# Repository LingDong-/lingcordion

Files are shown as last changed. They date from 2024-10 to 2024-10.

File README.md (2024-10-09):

# Lingcordion

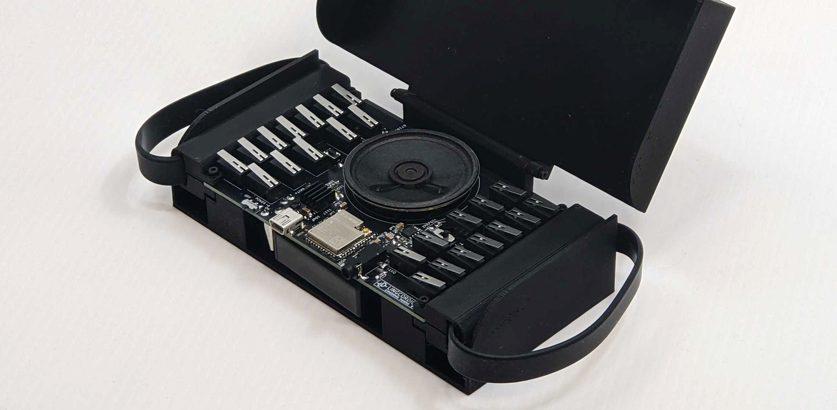
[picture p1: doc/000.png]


A pocket-sized digital musical instrument inspired by the piano and the accordion.

This repo hosts the design files of the PCB, source code for the firmware, and CAD parts for 3D printing.

## Features

- 3 playable octaves on the right hand, bass/chord mode on the left hand.
- On-board synthesizer / MIDI output (USB).
- On-board speaker / 3.5mm audio jack.
- Easy to learn, fits in your back pocket.

## How to Play

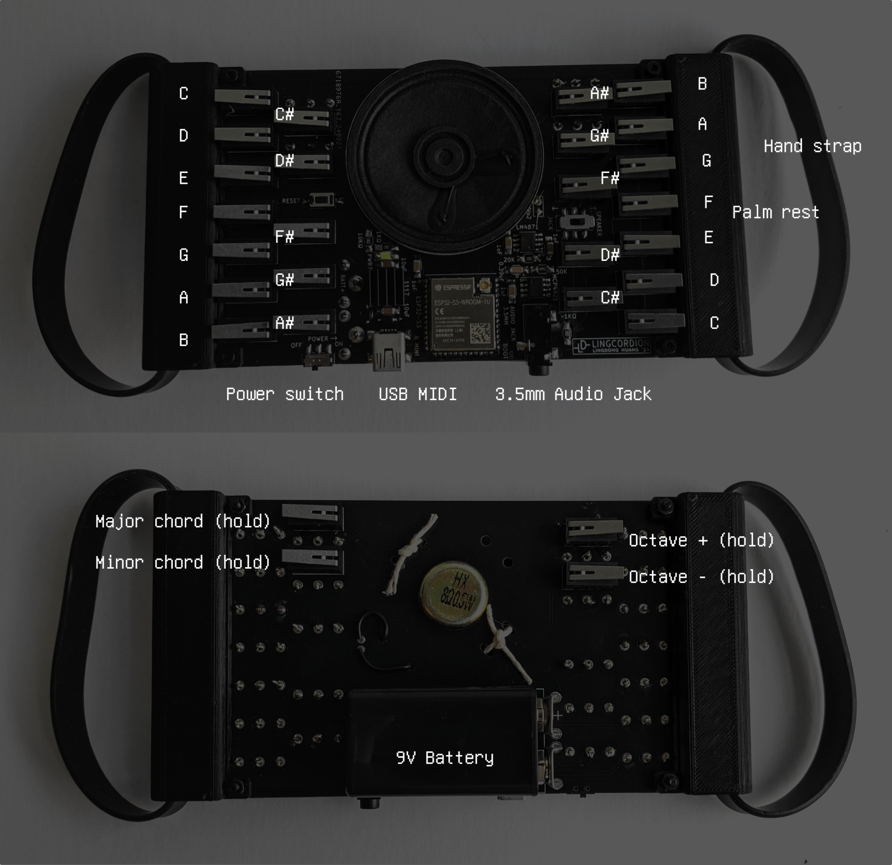
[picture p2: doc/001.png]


[Here's a video of me playing the instrument.](doc/v01.mp4)

https://github.com/user-attachments/assets/264b68fd-24f3-4782-8792-03d39f5a074a

- The index, middle, ring and (optionally) pinky fingers go between the strap and the palm rest, to play note keys on the front side.
- The thumbs press and hold modifier keys on the back side.

## BOM

- 28 limit switches
- ESP32-S3 module with more than 4 MB of flash
- LM4871 for audio power amplifier
- MCP4921 for DAC
- Assorted 1206 resistors capacitors. Misc. buttons and switches. 1117 3.3V regulator.

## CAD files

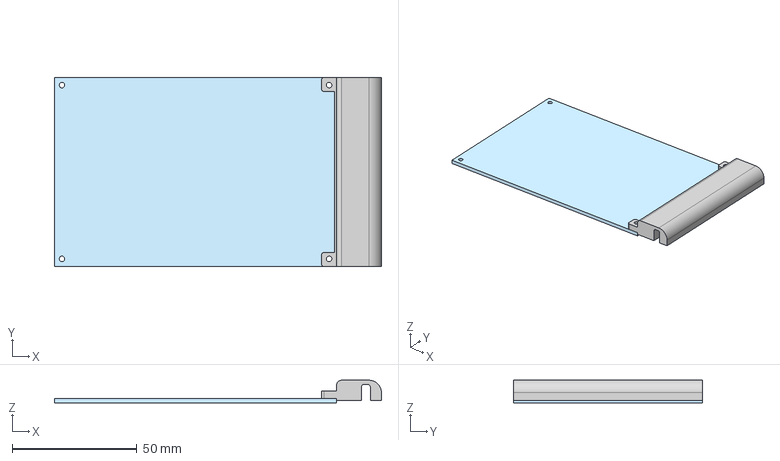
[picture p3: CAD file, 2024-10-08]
parts/rest.step
131.0 x 75.6 x 9.05 mm

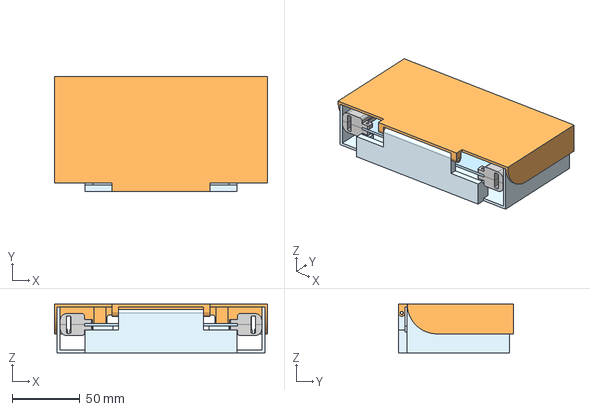
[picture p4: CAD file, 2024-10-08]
parts/case.step
157.4 x 85.1 x 36.0 mm

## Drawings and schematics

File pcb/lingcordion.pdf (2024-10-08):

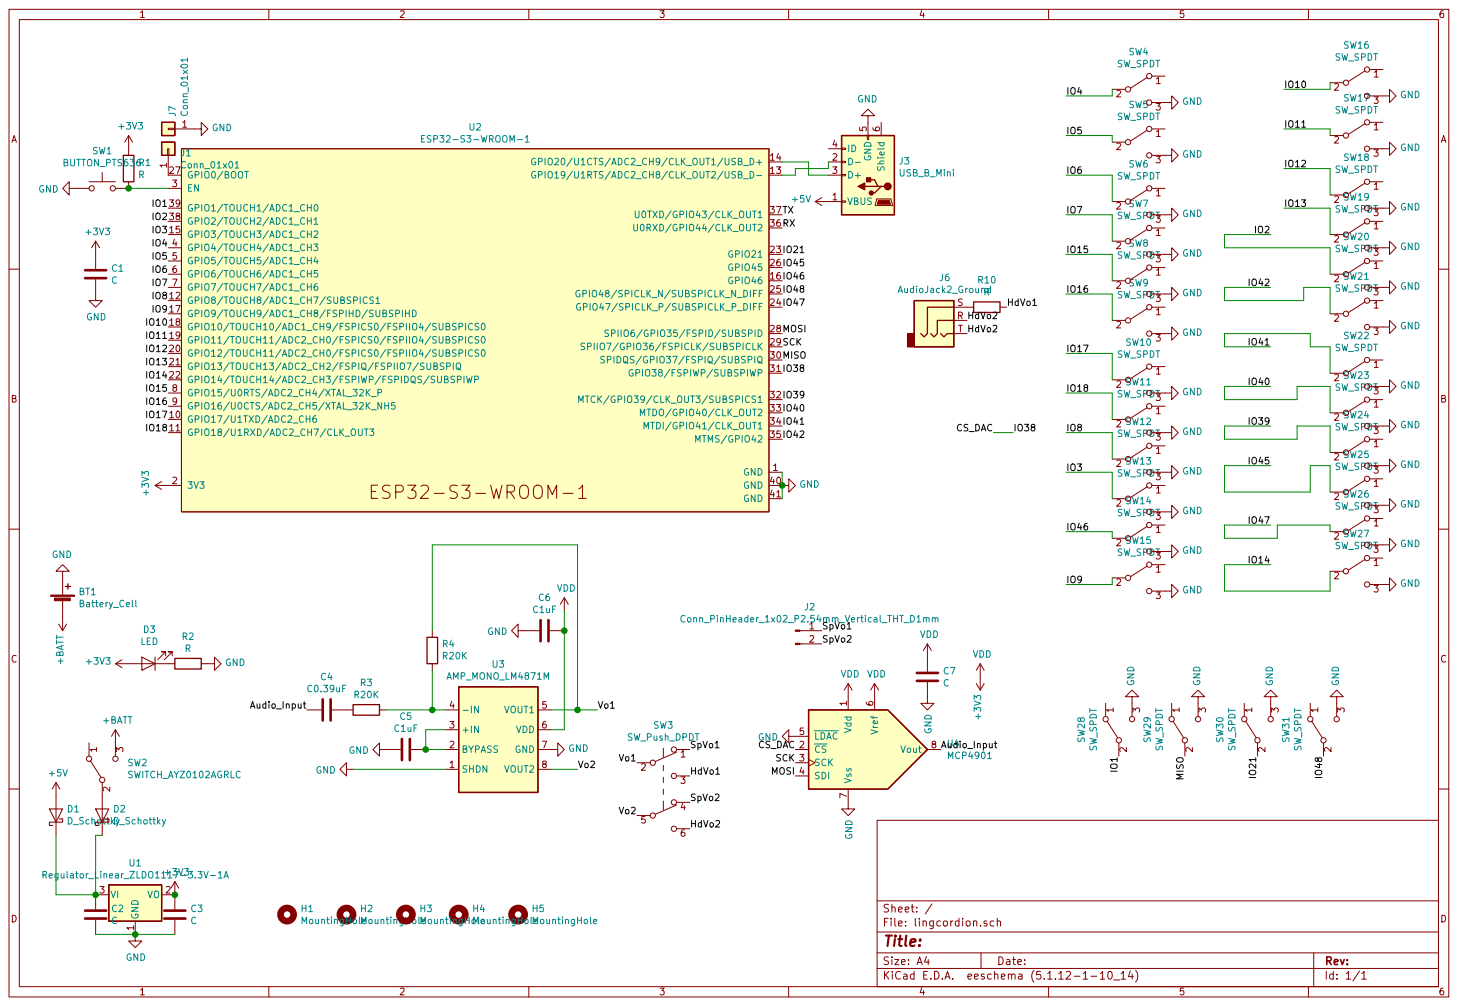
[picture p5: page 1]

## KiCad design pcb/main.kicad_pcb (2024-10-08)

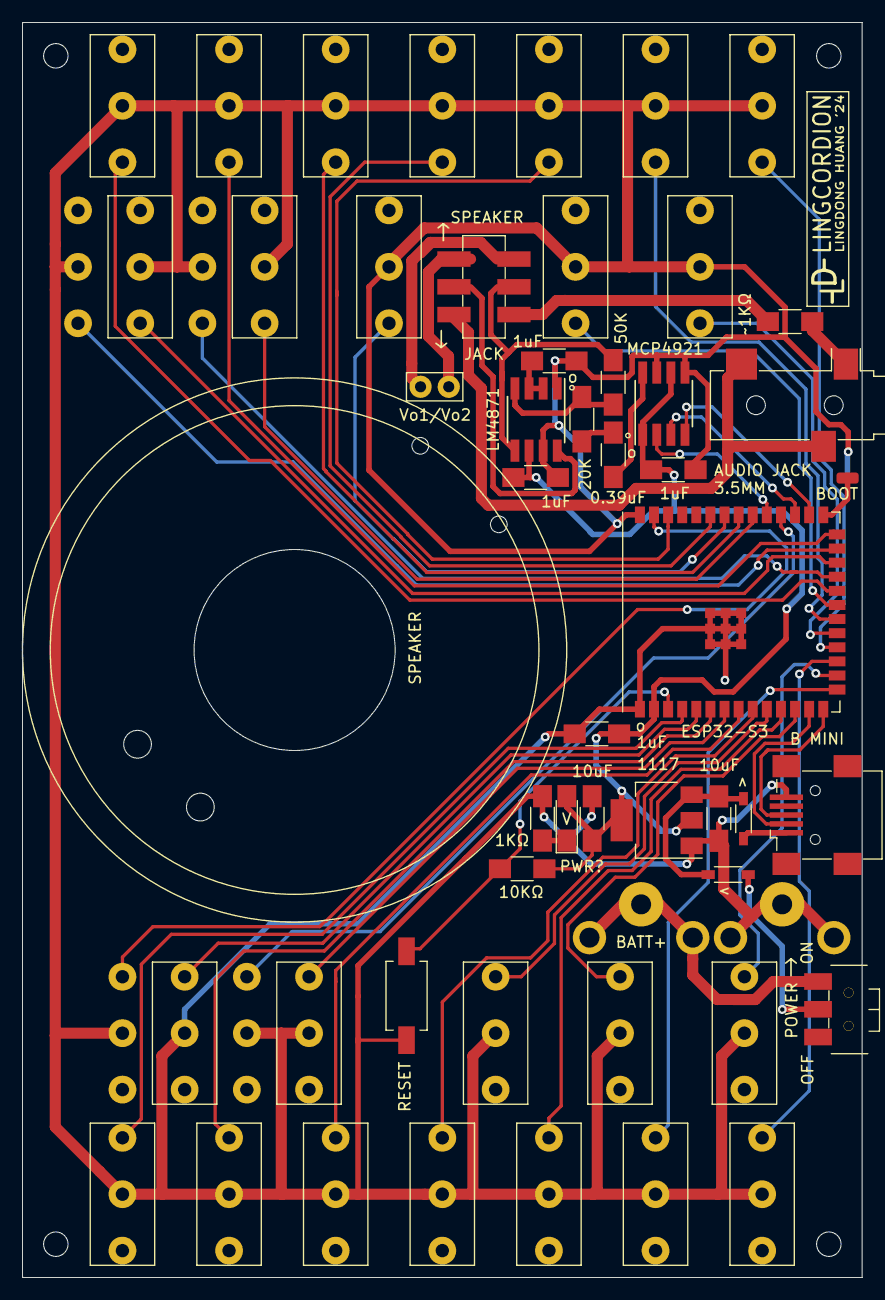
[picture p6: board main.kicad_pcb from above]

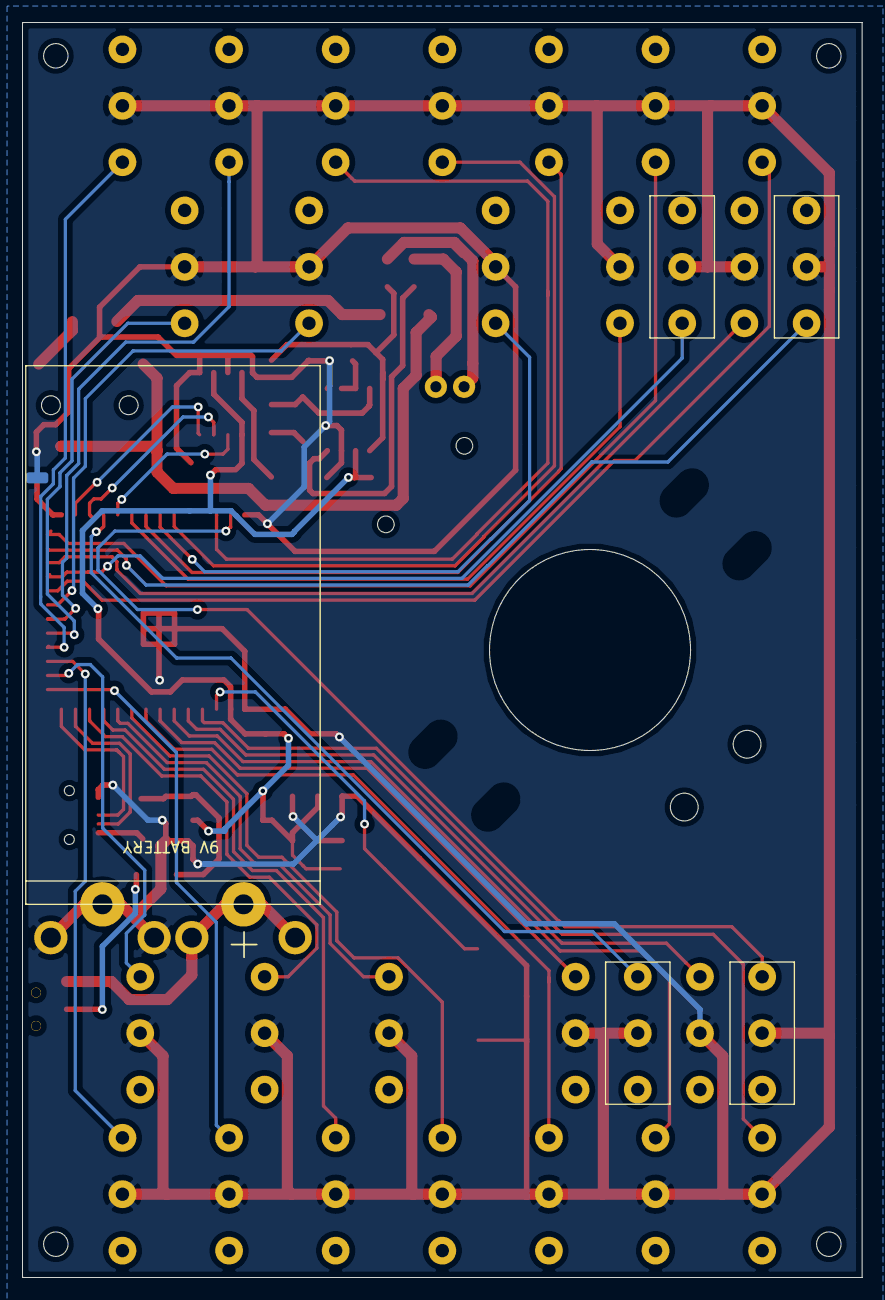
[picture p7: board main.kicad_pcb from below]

Board: 2 copper layers, 75.6 x 113.0 mm, 61 parts (6 on the bottom side), 53 nets.

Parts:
BT1: Battery_Cell; 9V_CONTACT_ON_BRD
C1, C2, C3, C7: C; C_1206
C4: C0.39uF; C_1206
C5, C6: C1uF; C_1206
D1, D2: D_Schottky; SOD-123
D3: LED; LED_1206
H1: MountingHole; SPEAKER_MOUNT
H2, H3, H4, H5: MountingHole; MountingHole_2.2mm_M2
J1, J7: Conn_01x01; SolderWirePad_1x01_SMD_1x2mm
J2: Conn_PinHeader_1x02_P2.54mm_Vertical_THT_D1mm; PinHeader_1x02_P2.54mm_Vertical_THT_D1mm
J3: USB_B_Mini; USB_Mini-B_Wuerth_65100516121_Horizontal
J6: AudioJack2_Ground; Jack_3.5mm_CUI_SJ-3523-SMT_Horizontal
R1, R2, R10: R; R_1206
R3, R4: R20K; R_1206
SW1: BUTTON_PTS636; Button_C&K_PTS636_6x3.5mm
SW2: SWITCH_AYZ0102AGRLC; Switch_SPDT_C&K_AYZ0102AGRLC_7.2x3mm_P2.5mm
SW3: SW_Push_DPDT; SW_DPDT_CK_JS202011JCQN
SW4, SW5, SW6, SW7, SW8, SW9, SW10, SW11, SW12, SW13, SW14, SW15, SW16, SW17, SW18, SW19, SW20, SW21, SW22, SW23, SW24, SW25, SW26, SW27, SW28, SW29, SW30, SW31: SW_SPDT; LIMIT_SWITCH_TE_SAJ
U1: Regulator_Linear_ZLDO1117-3.3V-1A; SOT-223-3_TabPin2
U2: ESP32-S3-WROOM-1
U3: AMP_MONO_LM4871M; SOIC-8_3.9x4.9mm_P1.27mm
U4: MCP4901; SOIC-8_3.9x4.9mm_P1.27mm

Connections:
+3V3: C1.1, C3.1, C6.1, C7.1, D3.2, R1.1, U1.2, U2.2, U3.6, U4.1, U4.6
+5V: D1.2, J3.1
+BATT: BT1.2, SW2.3
/Audio_Input: C4.2, U4.8
/CS_DAC: U2.31, U4.2
/HdVo1: R10.1, SW3.3
/HdVo2: J6.R, J6.T, SW3.6
/IO1: SW28.2, U2.39
/IO2: SW20.2, U2.38
/IO3: SW13.2, U2.15
/IO4: SW4.2, U2.4
/IO5: SW5.2, U2.5
/IO6: SW6.2, U2.6
/IO7: SW7.2, U2.7
/IO8: SW12.2, U2.12
/IO9: SW15.2, U2.17
/IO10: SW16.2, U2.18
/IO11: SW17.2, U2.19
/IO12: SW18.2, U2.20
/IO13: SW19.2, U2.21
/IO14: SW27.2, U2.22
/IO15: SW8.2, U2.8
/IO16: SW9.2, U2.9
/IO17: SW10.2, U2.10
/IO18: SW11.2, U2.11
/IO21: SW30.2, U2.23
/IO39: SW24.2, U2.32
/IO40: SW23.2, U2.33
/IO41: SW22.2, U2.34
/IO42: SW21.2, U2.35
/IO45: SW25.2, U2.26
/IO46: SW14.2, U2.16
/IO47: SW26.2, U2.24
/IO48: SW31.2, U2.25
/MISO: SW29.2, U2.30
/MOSI: U2.28, U4.4
/SCK: U2.29, U4.3
/SpVo1: J2.1, SW3.1
/SpVo2: J2.2, SW3.4
/Vo1: R4.2, SW3.2, U3.5
/Vo2: SW3.5, U3.8
GND: BT1.1, C1.2, C2.2, C3.2, C5.2, C6.2, C7.2, J3.5, J7.1, R2.1, SW1.1, SW4.3, SW5.3, SW6.3, SW7.3, SW8.3, SW9.3, SW10.3, SW11.3, SW12.3, SW13.3, SW14.3, SW15.3, SW16.3, SW17.3, SW18.3, SW19.3, SW20.3, SW21.3, SW22.3, SW23.3, SW24.3, SW25.3, SW26.3, SW27.3, SW28.3, SW29.3, SW30.3, SW31.3, U1.1, U2.1, U2.40, U2.41, U3.1, U3.7, U4.5, U4.7
unnamed: C2.1, D1.1, D2.1, U1.3
unnamed: C4.1, R3.2
unnamed: C5.1, U3.2, U3.3
unnamed: D2.2, SW2.2
unnamed: D3.1, R2.2
unnamed: J1.1, U2.27
unnamed: J3.2, U2.13
unnamed: J3.3, U2.14
unnamed: J6.S, R10.2
unnamed: R1.2, SW1.2, U2.3
unnamed: R3.1, R4.1, U3.4

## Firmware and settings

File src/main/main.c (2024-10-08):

#include <stdio.h>
#include <inttypes.h>
#include <string.h>
#include <math.h>
#include <dirent.h>
#include "sdkconfig.h"
#include "freertos/FreeRTOS.h"
#include "freertos/task.h"
#include "driver/spi_master.h"
#include "driver/gpio.h"
#include "esp_system.h"
#include "nvs_flash.h"
#include "driver/uart.h"

#include "tinyusb.h"

#include "esp_timer.h"


#define PIN_MOSI (35)
#define PIN_CLK  (36)
#define PIN_DACS (38)


#define PIN_OP (1)
#define PIN_OM (37)
#define PIN_CH (48)
#define PIN_BO (21)

#define MIDI_NOTE_OFF 0x80
#define MIDI_NOTE_ON  0x90

#define N_KEY 24

typedef struct key_st{
  uint8_t pitch;
  uint8_t flag;
  uint16_t onoff;
  uint16_t plyhd;
} KEY_t;

KEY_t keys[N_KEY]={0};

#define SAMP_RATE 8000

#define SAMP_PER_KEY 16000

#define TAPER 1000

spi_device_handle_t spi;

#define N_TBTN 24
static const int tbtn[N_TBTN] = {
  10,11,12,13,2,42,41,40,39,45,47,14,
  4,5,6,7,15,16,17,18,8,3,46,9
};



uint8_t tbtn_prev[N_TBTN] = {0};

int op_prv = 1;
int om_prv = 1;

int ch_prv = 1;
int bo_prv = 1;

#define GETSAMP(p) {\
  int idx = (((p)-21)*SAMP_PER_KEY+b)*2;\
  int A = ((uint8_t*)salaman)[idx];\
  int B = ((uint8_t*)salaman)[idx+1];\
  int16_t C = (A|(B<<8));\
  y = (float)C/32768.0;\
}


enum interface_count {
  ITF_NUM_MIDI = 0,
  ITF_NUM_MIDI_STREAMING,
  ITF_COUNT
};
enum usb_endpoints {
  EP_EMPTY = 0,
  EPNUM_MIDI,
};
#define TUSB_DESCRIPTOR_TOTAL_LEN (TUD_CONFIG_DESC_LEN + CFG_TUD_MIDI * TUD_MIDI_DESC_LEN)
static const char* s_str_desc[5] = {
  (char[]){0x09, 0x04},  // 0: is supported language is English (0x0409)
  "Lingdong Huang",      // 1: Manufacturer
  "Lingcordion",         // 2: Product
  "123456",              // 3: Serials, should use chip ID
  "MIDI device",         // 4: MIDI
};

static const uint8_t s_midi_cfg_desc[] = {
  TUD_CONFIG_DESCRIPTOR(1, ITF_COUNT, 0, TUSB_DESCRIPTOR_TOTAL_LEN, 0, 100),
  TUD_MIDI_DESCRIPTOR(ITF_NUM_MIDI, 4, EPNUM_MIDI, (0x80 | EPNUM_MIDI), 64),
};

void midi_note_on(int pitch, int vel){
  if (tud_midi_mounted()) {
    static uint8_t const cable_num = 0;
    static uint8_t const channel = 0;
    uint8_t note_on[3] = {MIDI_NOTE_ON | channel, pitch, vel};
    tud_midi_stream_write(cable_num, note_on, 3);
  }
}
void midi_note_off(int pitch){
  if (tud_midi_mounted()) {
    static uint8_t const cable_num = 0;
    static uint8_t const channel = 0;
    uint8_t note_off[3] = {MIDI_NOTE_OFF | channel, pitch, 0};
    tud_midi_stream_write(cable_num, note_off, 3);
  }
}

void core1_task(){
  tinyusb_config_t const tusb_cfg = {
    .device_descriptor = NULL,
    .string_descriptor = s_str_desc,
    .external_phy = false,
    .configuration_descriptor = s_midi_cfg_desc,
  };
  ESP_ERROR_CHECK(tinyusb_driver_install(&tusb_cfg));

  int idx = 0;
  uint8_t btn_prev[N_TBTN] = {0};
  int pit_prev[N_TBTN] = {0};

  while (1){
    int op = gpio_get_level(PIN_OP);
    int om = gpio_get_level(PIN_OM);
    int ch = gpio_get_level(PIN_CH);
    int bo = gpio_get_level(PIN_BO);

    int touch_value = gpio_get_level(tbtn[idx]);

    if (!touch_value && btn_prev[idx]){
      int p = 48+idx;
      if (idx < 12){
        if (!ch){
          midi_note_on(p,96);
          midi_note_on(p+4,96);
          midi_note_on(p+7,96);
          pit_prev[idx] = 0x100|p;
        }else if (!bo){
          midi_note_on(p,96);
          midi_note_on(p+3,96);
          midi_note_on(p+7,96);
          pit_prev[idx] = 0x200|p;
        }else{
          midi_note_on(p,96);
          pit_prev[idx] = p;
        }
      }else{
        if (!op){
          p += 12;
        }else if (!om){
          p -= 12;
        }
        midi_note_on(p,127);
        pit_prev[idx] = p;
      }

    }else if (touch_value  && !btn_prev[idx]){
      int p  = pit_prev[idx];
      if (p & 0x100){
        midi_note_off(p);
        midi_note_off(p+4);
        midi_note_off(p+7);
      }else if (p & 0x200){
        midi_note_off(p);
        midi_note_off(p+3);
        midi_note_off(p+7);
      }else{
        midi_note_off(p);
      }
    }
    btn_prev[idx] = touch_value;
    idx = (idx+1)%N_TBTN;
  }
}


void app_main(void){  


  const esp_partition_t* datapart = esp_partition_find_first(ESP_PARTITION_TYPE_DATA, ESP_PARTITION_SUBTYPE_DATA_UNDEFINED, "data");

  const void* salaman;
  esp_partition_mmap_handle_t handle;
  ESP_ERROR_CHECK(esp_partition_mmap(
      datapart,
      0,
      2848000,
      ESP_PARTITION_MMAP_DATA,
      &salaman,
      &handle
  ));

  for (int i = 0; i < N_TBTN; i++) {
    gpio_config_t io_conf;
    io_conf.intr_type = GPIO_INTR_DISABLE;
    io_conf.mode = GPIO_MODE_INPUT;
    io_conf.pin_bit_mask = (1ULL << tbtn[i]);
    io_conf.pull_down_en = GPIO_PULLDOWN_DISABLE;
    io_conf.pull_up_en = GPIO_PULLUP_ENABLE;     
    gpio_config(&io_conf);

    tbtn_prev[i] = 1;
  }


  esp_err_t ret;
  spi_bus_config_t buscfg={
    .miso_io_num=-1,
    .mosi_io_num=PIN_MOSI,
    .sclk_io_num=PIN_CLK,
    .quadwp_io_num=-1,
    .quadhd_io_num=-1,
    .max_transfer_sz=32
  };
  spi_device_interface_config_t devcfg={
    .clock_speed_hz=20*1000*1000, 
    .mode=0,                               
    .spics_io_num=PIN_DACS,  
    .flags=0,
    .queue_size=7,                      
  };
  ret=spi_bus_initialize(SPI2_HOST, &buscfg, SPI_DMA_CH_AUTO);
  ESP_ERROR_CHECK(ret);
  ret=spi_bus_add_device(SPI2_HOST, &devcfg, &spi);
  ESP_ERROR_CHECK(ret);


  {
    gpio_config_t io_conf;
    io_conf.intr_type = GPIO_INTR_DISABLE;
    io_conf.mode = GPIO_MODE_INPUT;
    io_conf.pin_bit_mask = (1ULL << PIN_OP);
    io_conf.pull_down_en = GPIO_PULLDOWN_DISABLE;
    io_conf.pull_up_en = GPIO_PULLUP_ENABLE;     
    gpio_config(&io_conf);
  }{
    gpio_config_t io_conf;
    io_conf.intr_type = GPIO_INTR_DISABLE;
    io_conf.mode = GPIO_MODE_INPUT;
    io_conf.pin_bit_mask = (1ULL << PIN_OM);
    io_conf.pull_down_en = GPIO_PULLDOWN_DISABLE;
    io_conf.pull_up_en = GPIO_PULLUP_ENABLE;     
    gpio_config(&io_conf);
  }{
    gpio_config_t io_conf;
    io_conf.intr_type = GPIO_INTR_DISABLE;
    io_conf.mode = GPIO_MODE_INPUT;
    io_conf.pin_bit_mask = (1ULL << PIN_CH);
    io_conf.pull_down_en = GPIO_PULLDOWN_DISABLE;
    io_conf.pull_up_en = GPIO_PULLUP_ENABLE;     
    gpio_config(&io_conf);
  }{
    gpio_config_t io_conf;
    io_conf.intr_type = GPIO_INTR_DISABLE;
    io_conf.mode = GPIO_MODE_INPUT;
    io_conf.pin_bit_mask = (1ULL << PIN_BO);
    io_conf.pull_down_en = GPIO_PULLDOWN_DISABLE;
    io_conf.pull_up_en = GPIO_PULLUP_ENABLE;     
    gpio_config(&io_conf);
  }

  uint8_t buf[2];
  spi_transaction_t tr;
  memset(&tr,0,sizeof(tr));
  tr.tx_buffer = buf;
  tr.length = 16;
  tr.flags = 0;  

  int tidx = 0;

  for (int i = 0; i < 24; i++){
    keys[i].pitch = 48+i;
  }


  xTaskCreatePinnedToCore(core1_task, "Core 1", 16384, NULL, 6, NULL, 1);

  while (1){
    int64_t start_time = esp_timer_get_time();

    int op = gpio_get_level(PIN_OP);
    int om = gpio_get_level(PIN_OM);
    int ch = gpio_get_level(PIN_CH);
    int bo = gpio_get_level(PIN_BO);

    float mag = 0;
    for (int j = 0; j < N_KEY; j++){
      if (keys[j].onoff){
        int b = keys[j].plyhd;
        float y = 0;
        if (b < SAMP_PER_KEY){
          int p = keys[j].pitch;
          if (j >= 12){
            if (!op){
              p += 12;
            }
            if (!om){
              p -= 12;
            }
          }
          if (j < 12 && !ch){
            GETSAMP(p);
            y *= 0.66*(float)keys[j].onoff/(float)TAPER;
            mag += y;

            GETSAMP(p+4);
            y *= 0.66*(float)keys[j].onoff/(float)TAPER;
            mag += y;

            GETSAMP(p+7);
            y *= 0.66*(float)keys[j].onoff/(float)TAPER;
            mag += y;

          }else if (j < 12 && !bo){
            GETSAMP(p);
            y *= 0.66*(float)keys[j].onoff/(float)TAPER;
            mag += y;

            GETSAMP(p+3);
            y *= 0.66*(float)keys[j].onoff/(float)TAPER;
            mag += y;

            GETSAMP(p+7);
            y *= 0.66*(float)keys[j].onoff/(float)TAPER;
            mag += y;

          }else{
            GETSAMP(p);
            y *= (float)keys[j].onoff/(float)TAPER;
            if (j < 12){
              y *= 0.66;
            }else{
              y *= 0.9;
            }
            mag += y;
          }
          if (keys[j].onoff < TAPER){
            keys[j].onoff--;
          }
        }else{
          keys[j].onoff = 0;
        }

      }
      keys[j].plyhd++;
    }

    uint32_t vvv = (fmin(fmax(mag,-1),1))*2047+2047;
    buf[0] = 0b00110000 | ((vvv>>8)&0xf);
    buf[1] = vvv&0xff;
    spi_device_polling_transmit(spi, &tr);

    int touch_value = gpio_get_level(tbtn[tidx]);





    if (!touch_value && tbtn_prev[tidx]){
      keys[tidx].onoff = TAPER;
      keys[tidx].plyhd = 0;
    }else if (touch_value  && !tbtn_prev[tidx]){
      if (keys[tidx].onoff == TAPER){
        keys[tidx].onoff = TAPER-1;
      }
    }
    tbtn_prev[tidx] = touch_value;
    tidx = (tidx+1)%N_TBTN;

    int64_t dt = esp_timer_get_time() - start_time;
    // printf("%d\n",ar);
    int wait = 125;

    if (dt > wait){
      printf("violation %lld\n", dt);
    }else{
      esp_rom_delay_us(wait-dt);
    }
  }


}
